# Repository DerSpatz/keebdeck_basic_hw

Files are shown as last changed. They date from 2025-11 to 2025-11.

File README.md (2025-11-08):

# KeebDeck Basic

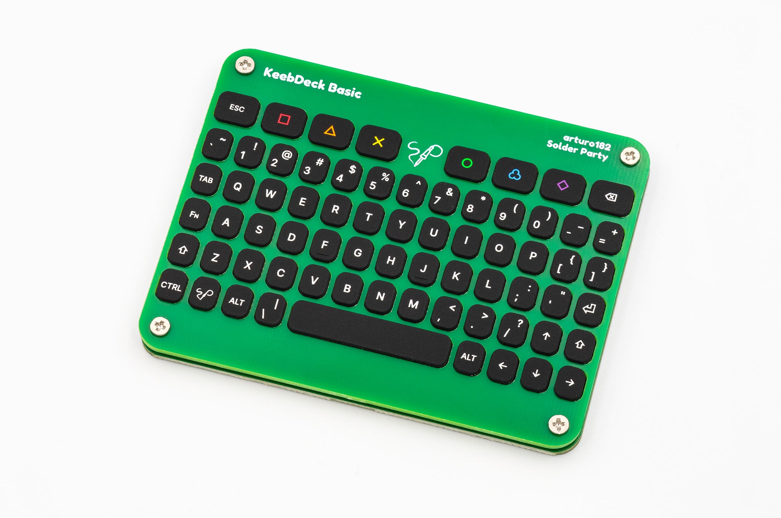
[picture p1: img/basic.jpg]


An affordable handheld QWERTY USB keyboard with a silicone keypad.

This is our first product using our KeebDeck Keyboard, meant to be a cost-effective way to demonstrate the capabilities of the Keyboard. It exposes the key presses as a **USB HID** over **USB Type-C**. The board also includes an unpopulated **Qwiic connector** footprint on the back, and test points with an I2C interface compatible with our previous BBQ10/BBQ20 boards.

For more information, visit https://docs.solder.party/keebdeck/basic

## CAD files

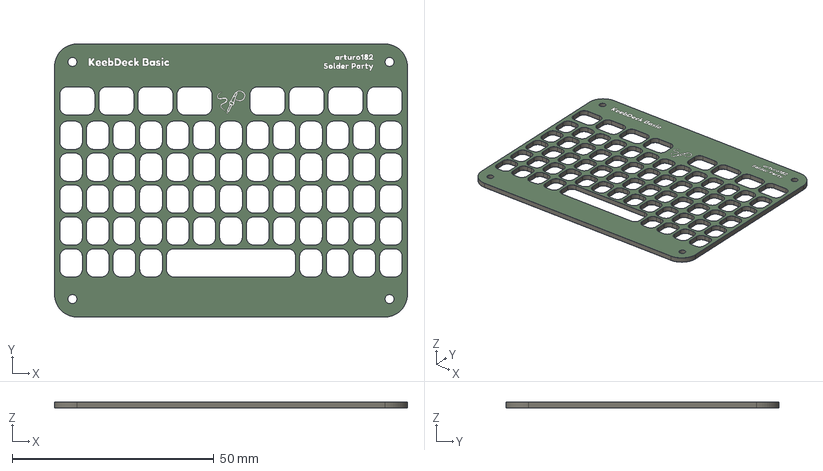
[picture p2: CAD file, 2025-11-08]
keebdeck_basic_faceplate.step
87.4 x 67.6 x 1.66 mm
keebdeck_basic_faceplate_silkscreen
keebdeck_basic_faceplate_soldermask
keebdeck_basic_faceplate_PCB

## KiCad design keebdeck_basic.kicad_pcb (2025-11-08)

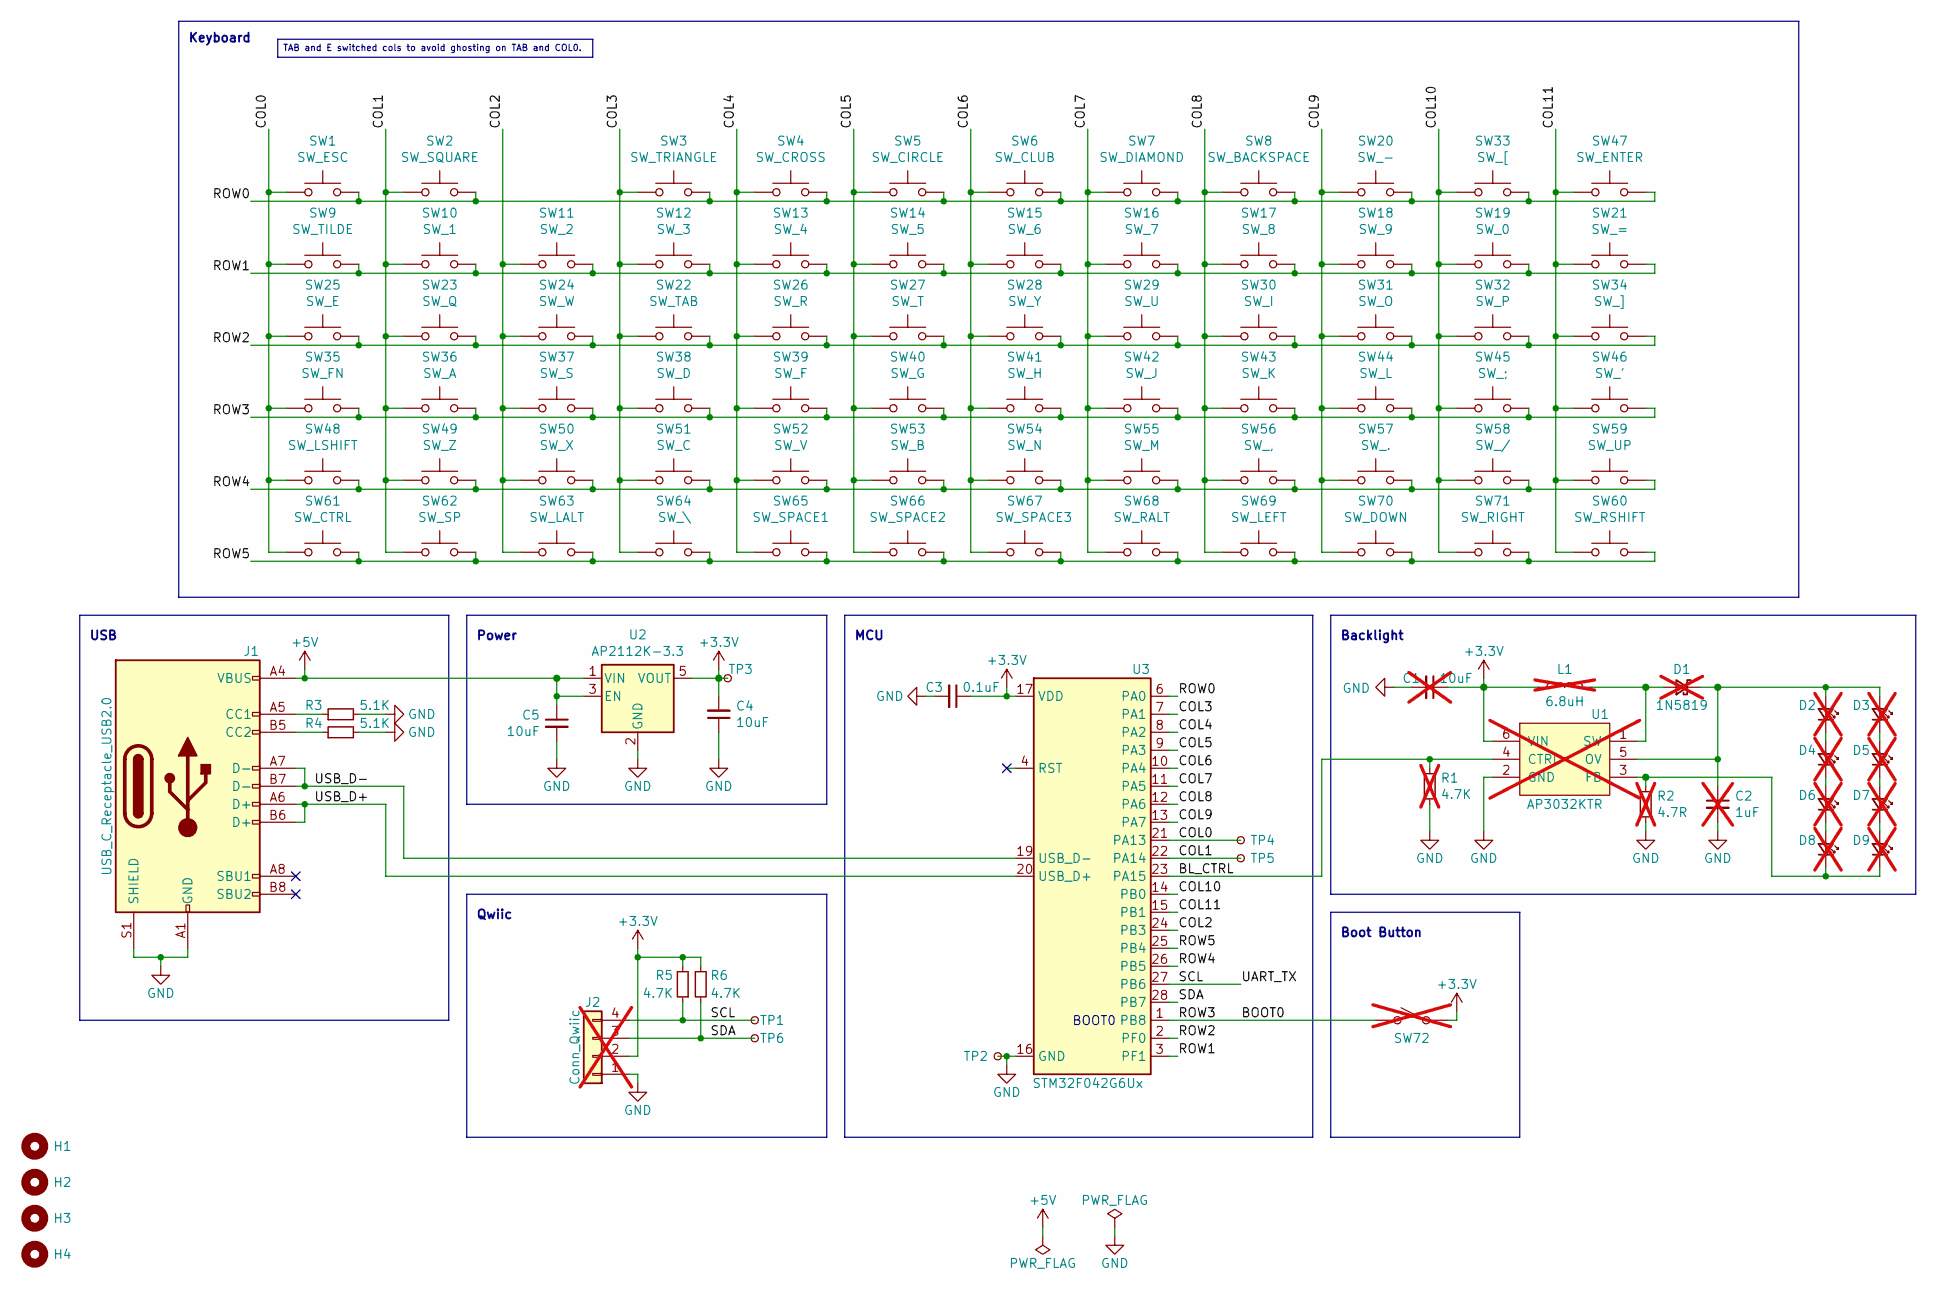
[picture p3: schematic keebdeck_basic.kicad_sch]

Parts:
C1: 10uF; C_0603_1608Metric; not fitted
C2: 1uF; C_0603_1608Metric; not fitted
C3: 0.1uF; C_0603_1608Metric
C4, C5: 10uF; C_0603_1608Metric
D1: 1N5819; D_SOD-323_HandSoldering; LCSC C369937; not fitted
D2, D3, D4, D5, D6, D7, D8, D9: LTW-010DCG-SR-G; LCSC C5175311; not fitted
H1, H2, H3, H4: MountingHole; SMD-1_BD4.4-D2.8; LCSC C5301775
J1: USB_C_Receptacle_USB2.0; USB_C_Receptacle_SHOU_HAN-TYPE-C-16P-CB1.6-073; LCSC C2906290
J2: Conn_Qwiic; JST_SH_SM04B-SRSS-TB_1x04-1MP_P1.00mm_Horizontal; LCSC C145956; not fitted
L1: 6.8uH; L_1008_2520Metric; LCSC C2041474; not fitted
R1: 4.7K; R_0603_1608Metric; not fitted
R2: 4.7R; R_0603_1608Metric; not fitted
R3, R4: 5.1K; R_0603_1608Metric
R5, R6: 4.7K; R_0603_1608Metric
SW1: SW_ESC; Metal_Dome_Oblong_5x4mm
SW2: SW_SQUARE; Metal_Dome_Oblong_5x4mm
SW3: SW_TRIANGLE; Metal_Dome_Oblong_5x4mm
SW4: SW_CROSS; Metal_Dome_Oblong_5x4mm
SW5: SW_CIRCLE; Metal_Dome_Oblong_5x4mm
SW6: SW_CLUB; Metal_Dome_Oblong_5x4mm
SW7: SW_DIAMOND; Metal_Dome_Oblong_5x4mm
SW8: SW_BACKSPACE; Metal_Dome_Oblong_5x4mm
SW9: SW_TILDE; Metal_Dome_Oblong_5x4mm
SW10: SW_1; Metal_Dome_Oblong_5x4mm
SW11: SW_2; Metal_Dome_Oblong_5x4mm
SW12: SW_3; Metal_Dome_Oblong_5x4mm
SW13: SW_4; Metal_Dome_Oblong_5x4mm
SW14: SW_5; Metal_Dome_Oblong_5x4mm
SW15: SW_6; Metal_Dome_Oblong_5x4mm
SW16: SW_7; Metal_Dome_Oblong_5x4mm
SW17: SW_8; Metal_Dome_Oblong_5x4mm
SW18: SW_9; Metal_Dome_Oblong_5x4mm
SW19: SW_0; Metal_Dome_Oblong_5x4mm
SW20: SW_-; Metal_Dome_Oblong_5x4mm
SW21: SW_=; Metal_Dome_Oblong_5x4mm
SW22: SW_TAB; Metal_Dome_Oblong_5x4mm
SW23: SW_Q; Metal_Dome_Oblong_5x4mm
SW24: SW_W; Metal_Dome_Oblong_5x4mm
SW25: SW_E; Metal_Dome_Oblong_5x4mm
SW26: SW_R; Metal_Dome_Oblong_5x4mm
SW27: SW_T; Metal_Dome_Oblong_5x4mm
SW28: SW_Y; Metal_Dome_Oblong_5x4mm
SW29: SW_U; Metal_Dome_Oblong_5x4mm
SW30: SW_I; Metal_Dome_Oblong_5x4mm
SW31: SW_O; Metal_Dome_Oblong_5x4mm
SW32: SW_P; Metal_Dome_Oblong_5x4mm
SW33: SW_[; Metal_Dome_Oblong_5x4mm
SW34: SW_]; Metal_Dome_Oblong_5x4mm
SW35: SW_FN; Metal_Dome_Oblong_5x4mm
SW36: SW_A; Metal_Dome_Oblong_5x4mm
SW37: SW_S; Metal_Dome_Oblong_5x4mm
SW38: SW_D; Metal_Dome_Oblong_5x4mm
SW39: SW_F; Metal_Dome_Oblong_5x4mm
SW40: SW_G; Metal_Dome_Oblong_5x4mm
SW41: SW_H; Metal_Dome_Oblong_5x4mm
SW42: SW_J; Metal_Dome_Oblong_5x4mm
SW43: SW_K; Metal_Dome_Oblong_5x4mm
SW44: SW_L; Metal_Dome_Oblong_5x4mm
SW45: SW_;; Metal_Dome_Oblong_5x4mm
SW46: SW_'; Metal_Dome_Oblong_5x4mm
SW47: SW_ENTER; Metal_Dome_Oblong_5x4mm
SW48: SW_LSHIFT; Metal_Dome_Oblong_5x4mm
SW49: SW_Z; Metal_Dome_Oblong_5x4mm
SW50: SW_X; Metal_Dome_Oblong_5x4mm
SW51: SW_C; Metal_Dome_Oblong_5x4mm
SW52: SW_V; Metal_Dome_Oblong_5x4mm
SW53: SW_B; Metal_Dome_Oblong_5x4mm
SW54: SW_N; Metal_Dome_Oblong_5x4mm
SW55: SW_M; Metal_Dome_Oblong_5x4mm
SW56: SW_,; Metal_Dome_Oblong_5x4mm
SW57: SW_.; Metal_Dome_Oblong_5x4mm
SW58: SW_/; Metal_Dome_Oblong_5x4mm
SW59: SW_UP; Metal_Dome_Oblong_5x4mm
SW60: SW_RSHIFT; Metal_Dome_Oblong_5x4mm
SW61: SW_CTRL; Metal_Dome_Oblong_5x4mm
SW62: SW_SP; Metal_Dome_Oblong_5x4mm
SW63: SW_LALT; Metal_Dome_Oblong_5x4mm
SW64: SW_\; Metal_Dome_Oblong_5x4mm
SW65: SW_SPACE1; Metal_Dome_Oblong_5x4mm
SW66: SW_SPACE2; Metal_Dome_Oblong_5x4mm
SW67: SW_SPACE3; Metal_Dome_Oblong_5x4mm
SW68: SW_RALT; Metal_Dome_Oblong_5x4mm
SW69: SW_LEFT; Metal_Dome_Oblong_5x4mm
SW70: SW_DOWN; Metal_Dome_Oblong_5x4mm
SW71: SW_RIGHT; Metal_Dome_Oblong_5x4mm
SW72: SW_BOOT; TS-1088R; LCSC C455280; not fitted
TP1: TP_SCL; TestPoint_Pad_D1.5mm
TP2, TP3: TP_UART_TX; TestPoint_Pad_D1.5mm
TP4: TP_SWDIO; TestPoint_Pad_D1.5mm
TP5: TP_SWCLK; TestPoint_Pad_D1.5mm
TP6: TP_SDA; TestPoint_Pad_D1.5mm
U1: AP3032KTR; SOT-23-6; LCSC C264086; not fitted
U2: AP2112K-3.3; SOT-23-5; LCSC C51118
U3: STM32F042G6Ux; QFN-28_4x4mm_P0.5mm; LCSC C961597

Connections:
+3.3V: C1.1, C3.1, C4.2, J2.2, L1.1, R5.2, R6.1, SW72.1 (A), TP3.1, U1.6 (VIN), U2.5 (VOUT), U3.5 (VDDA), U3.17 (VDD), U3.18 (VDDIO2)
+5V: C5.1, J1.A4 (VBUS), J1.A9 (VBUS), J1.B4 (VBUS), J1.B9 (VBUS), U2.1 (VIN), U2.3 (EN)
/BL_CTRL: R1.2, U1.4 (CTRL), U3.23 (PA15)
/BOOT0: SW35.2, SW36.2, SW37.2, SW38.2, SW39.2, SW40.2, SW41.2, SW42.2, SW43.2, SW44.2, SW45.2, SW46.2, SW72.2 (B), U3.1 (PB8)
/COL0: SW1.1, SW9.1, SW25.1, SW35.1, SW48.1, SW61.1, TP4.1, U3.21 (PA13)
/COL1: SW2.1, SW10.1, SW23.1, SW36.1, SW49.1, SW62.1, TP5.1, U3.22 (PA14)
/COL2: SW11.1, SW24.1, SW37.1, SW50.1, SW63.1, U3.24 (PB3)
/COL3: SW3.1, SW12.1, SW22.1, SW38.1, SW51.1, SW64.1, U3.7 (PA1)
/COL4: SW4.1, SW13.1, SW26.1, SW39.1, SW52.1, SW65.1, U3.8 (PA2)
/COL5: SW5.1, SW14.1, SW27.1, SW40.1, SW53.1, SW66.1, U3.9 (PA3)
/COL6: SW6.1, SW15.1, SW28.1, SW41.1, SW54.1, SW67.1, U3.10 (PA4)
/COL7: SW7.1, SW16.1, SW29.1, SW42.1, SW55.1, SW68.1, U3.11 (PA5)
/COL8: SW8.1, SW17.1, SW30.1, SW43.1, SW56.1, SW69.1, U3.12 (PA6)
/COL9: SW18.1, SW20.1, SW31.1, SW44.1, SW57.1, SW70.1, U3.13 (PA7)
/COL10: SW19.1, SW32.1, SW33.1, SW45.1, SW58.1, SW71.1, U3.14 (PB0)
/COL11: SW21.1, SW34.1, SW46.1, SW47.1, SW59.1, SW60.1, U3.15 (PB1)
/ROW0: SW1.2, SW2.2, SW3.2, SW4.2, SW5.2, SW6.2, SW7.2, SW8.2, SW20.2, SW33.2, SW47.2, U3.6 (PA0)
/ROW1: SW9.2, SW10.2, SW11.2, SW12.2, SW13.2, SW14.2, SW15.2, SW16.2, SW17.2, SW18.2, SW19.2, SW21.2, U3.3 (PF1)
/ROW2: SW22.2, SW23.2, SW24.2, SW25.2, SW26.2, SW27.2, SW28.2, SW29.2, SW30.2, SW31.2, SW32.2, SW34.2, U3.2 (PF0)
/ROW4: SW48.2, SW49.2, SW50.2, SW51.2, SW52.2, SW53.2, SW54.2, SW55.2, SW56.2, SW57.2, SW58.2, SW59.2, U3.26 (PB5)
/ROW5: SW60.2, SW61.2, SW62.2, SW63.2, SW64.2, SW65.2, SW66.2, SW67.2, SW68.2, SW69.2, SW70.2, SW71.2, U3.25 (PB4)
/SCL: J2.4, R5.1, TP1.1, U3.27 (PB6)
/SDA: J2.3, R6.2, TP6.1, U3.28 (PB7)
/USB_D+: J1.A6 (D+), J1.B6 (D+), U3.20 (USB_D+)
/USB_D-: J1.A7 (D-), J1.B7 (D-), U3.19 (USB_D-)
GND: C1.2, C2.2, C3.2, C4.1, C5.2, J1.A1 (GND), J1.A12 (GND), J1.B1 (GND), J1.B12 (GND), J1.S1 (SHIELD), J2.1, R1.1, R2.2, R3.2, R4.2, TP2.1, U1.2 (GND), U2.2 (GND), U3.16 (GND)
unnamed: D1.2 (A), L1.2, U1.1 (SW)
unnamed: C2.1, D1.1 (K), D2.2 (A), D3.2 (A), U1.5 (OV)
unnamed: D2.1 (K), D4.2 (A)
unnamed: D3.1 (K), D5.2 (A)
unnamed: D4.1 (K), D6.2 (A)
unnamed: D5.1 (K), D7.2 (A)
unnamed: D6.1 (K), D8.2 (A)
unnamed: D7.1 (K), D9.2 (A)
unnamed: D8.1 (K), D9.1 (K), R2.1, U1.3 (FB)
unnamed: J1.A5 (CC1), R3.1
unnamed: J1.B5 (CC2), R4.1

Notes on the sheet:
Keyboard
Boot Button
USB
Backlight
Qwiic
BOOT0
MCU
Power
TAB and E switched cols to avoid ghosting on TAB and COL0.

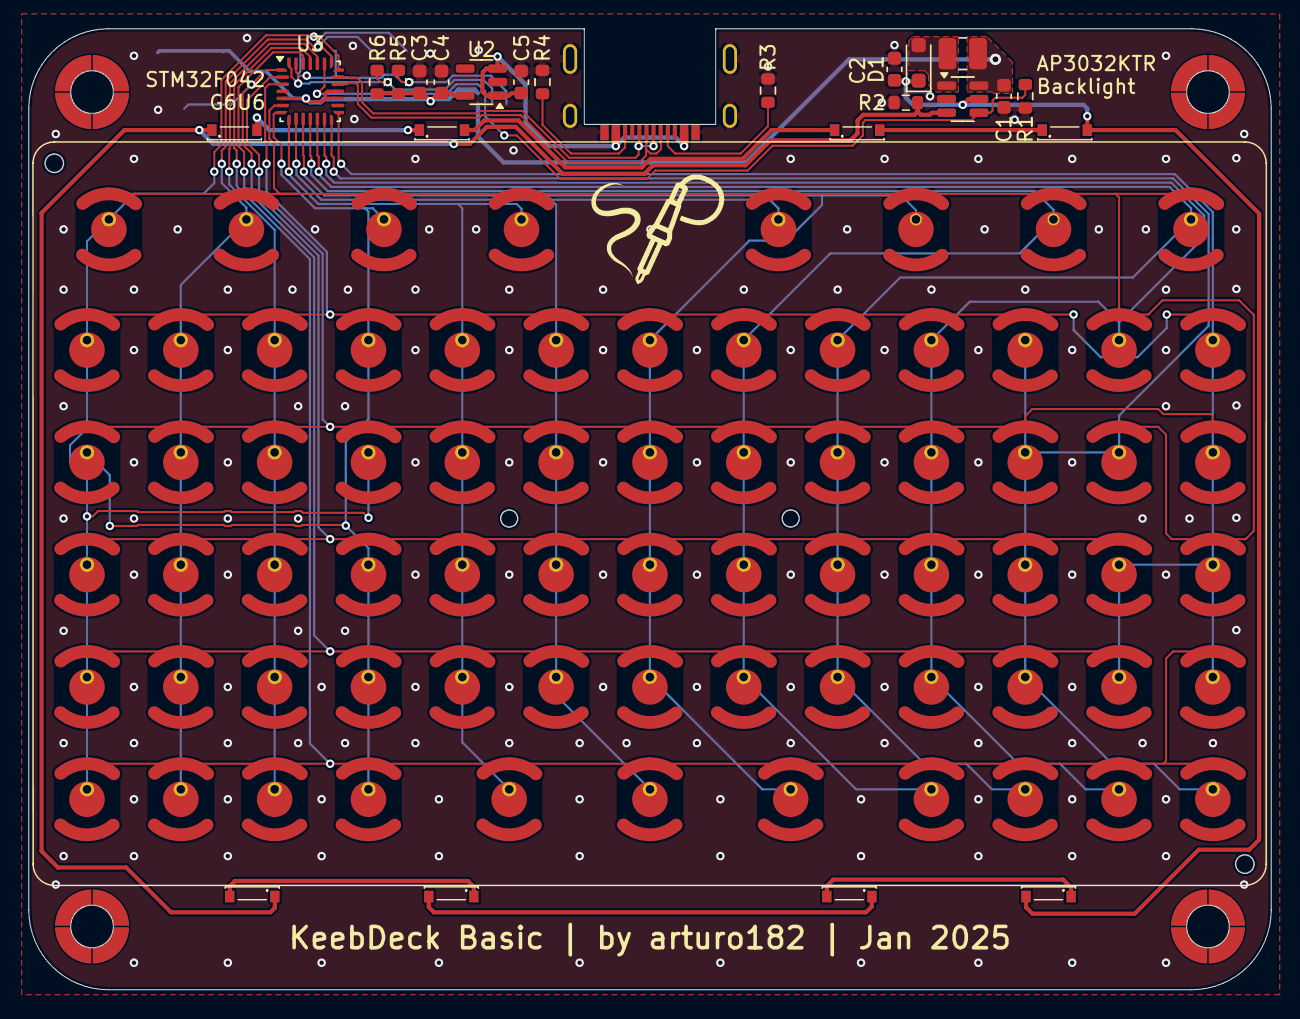
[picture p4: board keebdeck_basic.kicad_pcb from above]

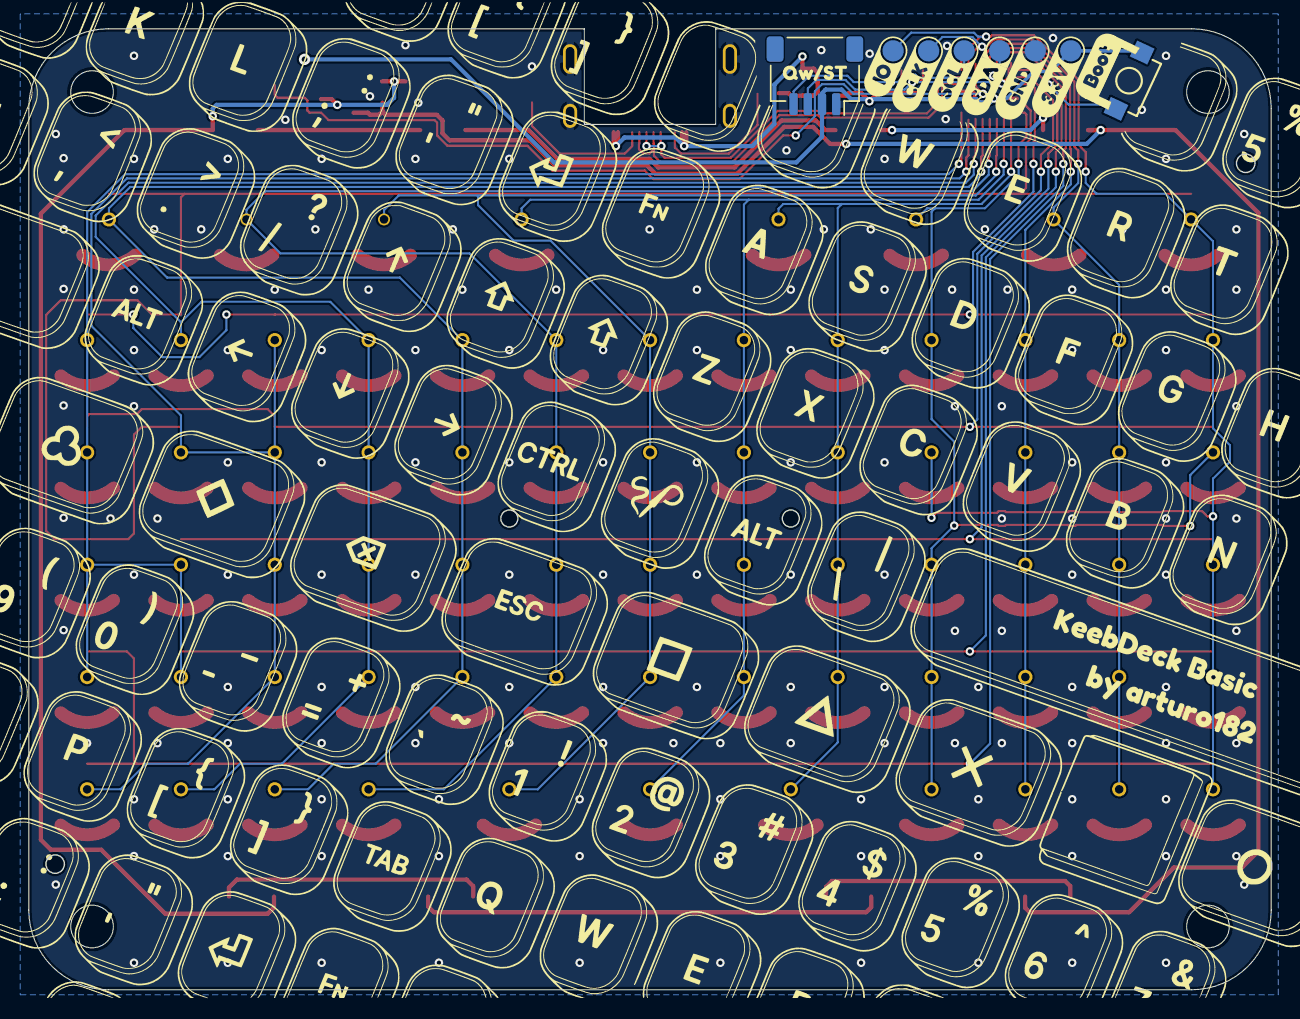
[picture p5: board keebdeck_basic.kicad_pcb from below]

Board: 2 copper layers, 87.4 x 67.6 mm, 118 parts (18 on the bottom side), 37 nets.

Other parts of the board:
kibuzzard-66E774B8: G***; kibuzzard-66E774B8
kibuzzard-67980A86: G***; kibuzzard-67980A86
kibuzzard-67980AB3: G***; kibuzzard-67980AB3
kibuzzard-67980AD7: G***; kibuzzard-67980AD7
kibuzzard-67980AE1: G***; kibuzzard-67980AE1
kibuzzard-67980AE6: G***; kibuzzard-67980AE6
kibuzzard-67980B11: G***; kibuzzard-67980B11
kibuzzard-67991D89: G***; kibuzzard-67991D89
kibuzzard-67991E3A: G***; kibuzzard-67991E3A
kibuzzard-6798348F: G***; kibuzzard-6798348F

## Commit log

2025-01-28 Rev 1
    [keebdeck_basic.kicad_pcb, keebdeck_basic.kicad_sch, keebdeck_basic_faceplate.kicad_pcb]
2025-11-08 Rev 1.1 - Production
    [keebdeck_basic.kicad_pcb, keebdeck_basic.kicad_sch, keebdeck_basic_faceplate.kicad_pcb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]
